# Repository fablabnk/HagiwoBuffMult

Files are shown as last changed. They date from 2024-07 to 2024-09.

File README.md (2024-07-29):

https://note.com/solder_state/n/n54e016f19c94#8e5c9ae0-af24-4910-aa9b-f91eed0dcada

- choosing to ignore issue that pads are too close to board edge by 0.03mm
- In future revision could add two 100n decoupling caps such as in [this design](https://www.skullandcircuits.com/utilities-buffered-multiple/?v=d3dcf429c679). Tried to add later on but it was too tight a squeeze.

# Build Instructions

S stands for socket
P stands for pin

# TODO

- check that two boards overlap

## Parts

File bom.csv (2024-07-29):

Reference | Value | Have It? | Datasheet | Footprint | Qty | DNP
C1,C2 | 100n | 104 | ~ | Capacitor_THT:CP_Radial_D5.0mm_P2.50mm | 2
IN1,IN2,OUT1,OUT2,OUT3,OUT4,OUT5,OUT6 | 3.5mm_Mono_Switched_sm | Y |  | PCM_4ms_Jack:EighthInch_PJ398SM | 8
J6,J7,J8,J10,J11,J12,J13,J14,J15,J16 | Conn_01x01_Pin | Y | ~ | Connector_PinHeader_2.54mm:PinHeader_1x01_P2.54mm_Vertical | 10
J9 | Eurorack_Power_10pin_Unshrouded | Y but order more from Ali |  | Library:IDC-Header_2x05_P2.54mm_Vertical_Euro_Power_Striped | 1
J17,J18,J19,J20,J21,J22,J23,J24,J25,J26 | Conn_01x01_Socket | Y | ~ | Connector_PinSocket_2.54mm:PinSocket_1x01_P2.54mm_Vertical | 10
R1,R2,R3,R4,R5,R6,R7,R8 | 330 | Y | ~ | Resistor_THT:R_Axial_DIN0207_L6.3mm_D2.5mm_P7.62mm_Horizontal | 8
U1,U2 | TL074 | Y but order more from Ali | http://www.ti.com/lit/ds/symlink/tl071.pdf | Package_DIP:DIP-14_W7.62mm_Socket | 2

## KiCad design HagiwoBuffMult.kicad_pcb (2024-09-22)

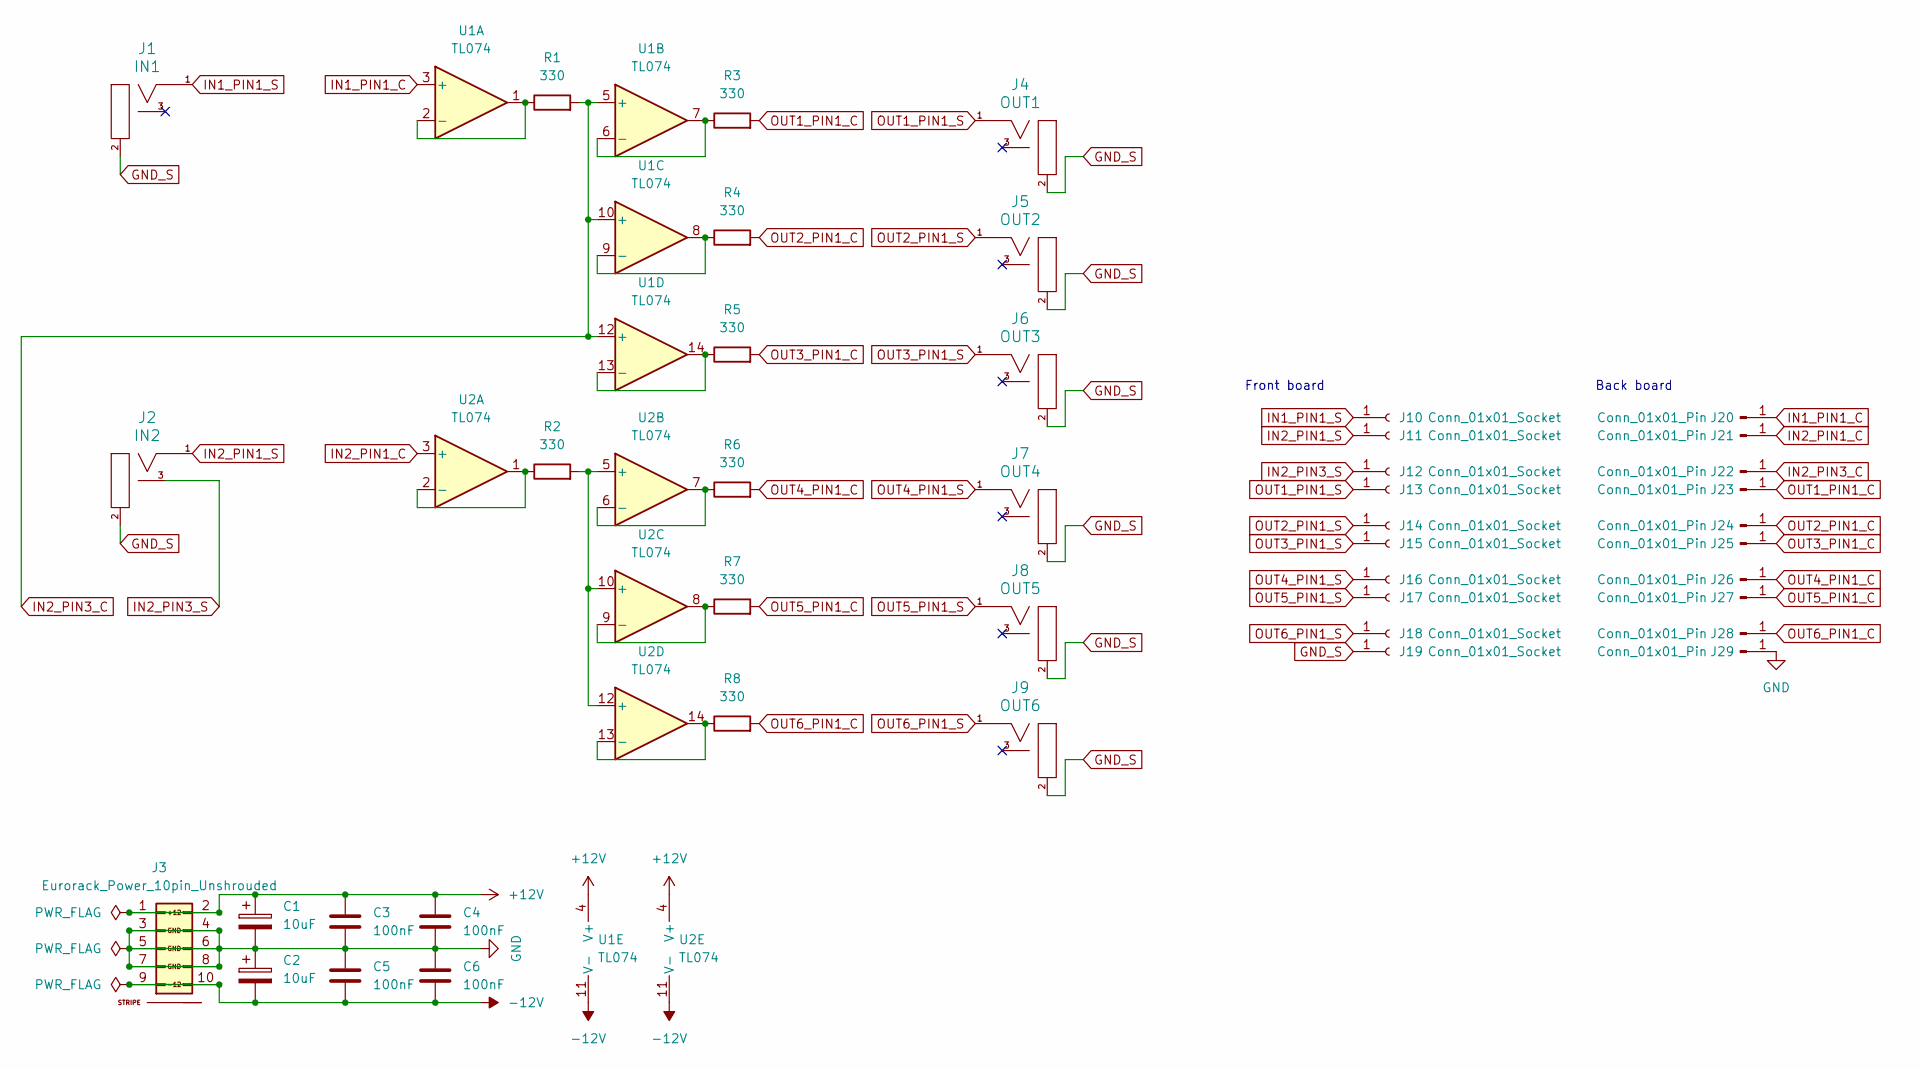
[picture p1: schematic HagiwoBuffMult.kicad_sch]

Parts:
C1, C2: 10uF; CP_Radial_D4.0mm_P2.00mm
C3, C4, C5, C6: 100nF; C_Disc_D3.0mm_W1.6mm_P2.50mm
J1: IN1; EighthInch_PJ398SM_3mmNPTH; Part Number WQP-WQP518MA
J2: IN2; EighthInch_PJ398SM_3mmNPTH; Part Number WQP-WQP518MA
J3: Eurorack_Power_10pin_Unshrouded; IDC-Header_2x05_P2.54mm_Vertical_Euro_Power_Striped_Thicker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; Part Number 1-1002FBV0T
J4: OUT1; EighthInch_PJ398SM_3mmNPTH; Part Number WQP-WQP518MA
J5: OUT2; EighthInch_PJ398SM_3mmNPTH; Part Number WQP-WQP518MA
J6: OUT3; EighthInch_PJ398SM_3mmNPTH; Part Number WQP-WQP518MA
J7: OUT4; EighthInch_PJ398SM_3mmNPTH; Part Number WQP-WQP518MA
J8: OUT5; EighthInch_PJ398SM_3mmNPTH; Part Number WQP-WQP518MA
J9: OUT6; EighthInch_PJ398SM_3mmNPTH; Part Number WQP-WQP518MA
J10, J11, J12, J13, J14, J15, J16, J17, J18, J19: Conn_01x01_Socket; PinSocket_1x01_P2.54mm_Vertical
J20, J21, J22, J23, J24, J25, J26, J27, J28, J29: Conn_01x01_Pin; PinHeader_1x01_P2.54mm_Vertical
R1, R2, R3, R4, R5, R6, R7, R8: 330; R_Axial_DIN0204_L3.6mm_D1.6mm_P1.90mm_Vertical
U1, U2: TL074; DIP-14_W7.62mm_Socket

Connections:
+12V: C1.1, C3.1, C4.1, J3.1 (+12V), J3.2 (+12V), U1.4 (V+), U2.4 (V+)
-12V: C2.2, C5.2, C6.2, J3.9 (-12V), J3.10 (-12V), U1.11 (V-), U2.11 (V-)
GND: C1.2, C2.1, C3.2, C4.2, C5.1, C6.1, J3.3 (GND), J3.4 (GND), J3.5 (GND), J3.6 (GND), J3.7 (GND), J3.8 (GND), J29.1
GND_S: J1.2 (SHEILD), J2.2 (SHEILD), J4.2 (SHEILD), J5.2 (SHEILD), J6.2 (SHEILD), J7.2 (SHEILD), J8.2 (SHEILD), J9.2 (SHEILD), J19.1
IN1_PIN1_C: J20.1, U1.3 (+)
IN1_PIN1_S: J1.1 (SIG), J10.1
IN2_PIN1_C: J21.1, U2.3 (+)
IN2_PIN1_S: J2.1 (SIG), J11.1
IN2_PIN3_C: J22.1, R1.2, U1.5 (+), U1.10 (+), U1.12 (+)
IN2_PIN3_S: J2.3 (SW), J12.1
unnamed: R1.1, U1.1, U1.2 (-)
unnamed: R3.1, U1.6 (-), U1.7
unnamed: R4.1, U1.8, U1.9 (-)
unnamed: R5.1, U1.13 (-), U1.14
unnamed: R2.1, U2.1, U2.2 (-)
unnamed: R2.2, U2.5 (+), U2.10 (+), U2.12 (+)
unnamed: R6.1, U2.6 (-), U2.7
unnamed: R7.1, U2.8, U2.9 (-)
unnamed: R8.1, U2.13 (-), U2.14
OUT1_PIN1_C: J23.1, R3.2
OUT1_PIN1_S: J4.1 (SIG), J13.1
OUT2_PIN1_C: J24.1, R4.2
OUT2_PIN1_S: J5.1 (SIG), J14.1
OUT3_PIN1_C: J25.1, R5.2
OUT3_PIN1_S: J6.1 (SIG), J15.1
OUT4_PIN1_C: J26.1, R6.2
OUT4_PIN1_S: J7.1 (SIG), J16.1
OUT5_PIN1_C: J27.1, R7.2
OUT5_PIN1_S: J8.1 (SIG), J17.1
OUT6_PIN1_C: J28.1, R8.2
OUT6_PIN1_S: J9.1 (SIG), J18.1

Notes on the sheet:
Back board
Front board

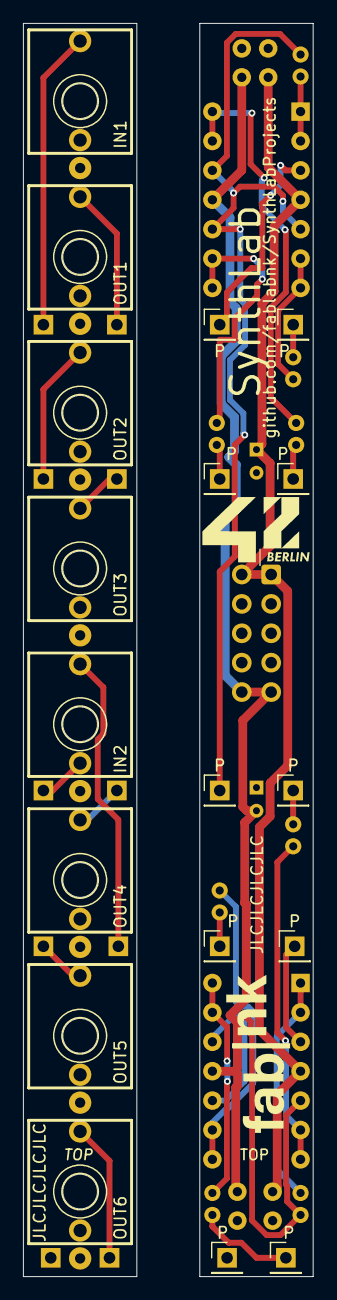
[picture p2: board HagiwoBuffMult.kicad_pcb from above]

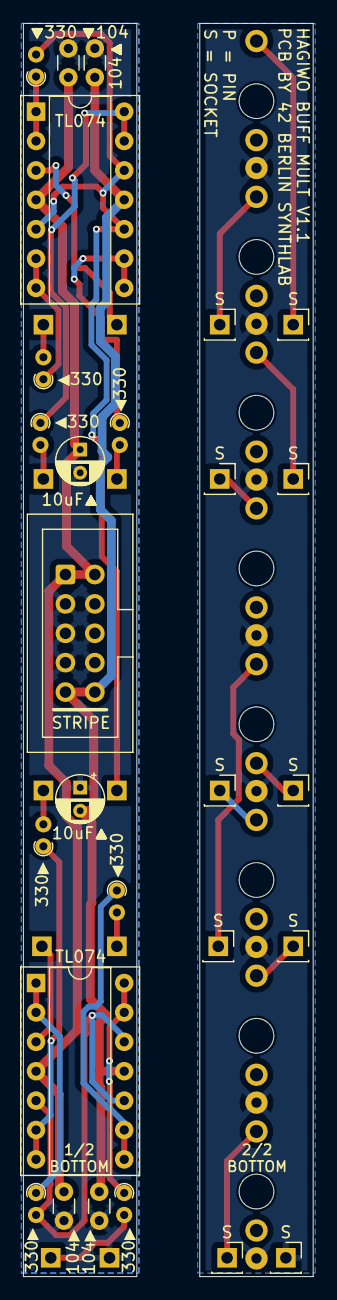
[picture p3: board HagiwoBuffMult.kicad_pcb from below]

Board: 2 copper layers, 25.0 x 108.3 mm, 45 parts (27 on the bottom side), 31 nets.

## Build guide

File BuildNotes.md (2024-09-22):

# V1.0

## Things to pay attention to whilst building
- cut down larger pin header sockets to single ones
- solder in jacks before pin sockets

## Design issues to fix in V1.1
- DONE: thicker traces 30 mil power 20 mil signal
- DONE: add 100nF caps
- DONE: optimise layout to minimise routing up and down the board
- DONE: widen 10uf cap footprint (hand soldering is tight)
- IGNORED: board edge clearance violation warnings

## Component issues

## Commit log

2024-07-29 addition of 100n decoupling cap causing complications
    [HagiwoBuffMult.kicad_pcb, HagiwoBuffMult.kicad_sch, bom.csv]
2024-07-29 routed and made panel
    [HagiwoBuffMult.kicad_pcb, HagiwoBuffMult.kicad_sch]
2024-08-04 broke panel out into separate file and made board and panel width narrower in accordance with doefper A100 standard
    [HagiwoBuffMult.kicad_pcb, HagiwoBuffMult_Panel.kicad_pcb]
2024-08-04 added branding and instructions
    [HagiwoBuffMult.kicad_pcb, HagiwoBuffMult.kicad_sch]
2024-08-11 v1.0 ready for production
    [HagiwoBuffMult.kicad_pcb, HagiwoBuffMult.kicad_sch, HagiwoBuffMult_Board1.kicad_pcb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]
2024-08-15 removed files for separate boards as in the end we will combine with other boards for production
    [HagiwoBuffMult_Board1.kicad_pcb, HagiwoBuffMult_Board2.kicad_pcb]
2024-09-15 working on v1.1 - added build notes - widened 10uF cap footprint - what to do about traces being too close to board edge?
    [HagiwoBuffMult.kicad_pcb, HagiwoBuffMult.kicad_sch, bom.csv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]
2024-09-22 v1.1 reaady for final check
    [HagiwoBuffMult.kicad_pcb, HagiwoBuffMult.kicad_sch]
